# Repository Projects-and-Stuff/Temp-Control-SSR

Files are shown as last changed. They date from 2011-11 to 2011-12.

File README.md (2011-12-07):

# Temp Control SSR #
#### A Solid State Relay designed to switch loads of up to 8A and up to 220VAC ####

I'm designing a Solid-State Relay circuit board which is controlled by a temperature sensor.

The original purpose for this project involves a story: As I'm writing this, I'm deployed in Afghanistan. We have somewhat limited resources for frivolous things, and apparently this extends to keeping foods and drinks cool. We were able to scrounge a freezer, and so we continuously have to open the freezer lid to thaw our milk, water, and foods. It's not the best set-up, but we cannot get a proper refrigerator out here.

So I set out to make a device to cut off the power to the freezer when it's overly cold, and turn it back on before the food gets warm. Because I'm using a microcontroller, I can experiment with carious feedback and control designs in software as I look for the best solution. I've designed the initial boards with terminals for the temperature sensor, so it's possible to modify the firmware for other types of sensors.

---

The current hardware iteration of this project is actually a bit over-engineered and large. A future design will shrink the board to a more manageable size, and reduce costs.

---

*File Structure*

* ./Firmware/ --> Firmware for the project (Written in C Utilizing AVR Studio 5 and AVRGCC)
* ./Hardware/ --> Kicad Project for TempControl Hardware
* ./GerberOutput/ --> The latest Gerber Files for manufacture
* ./Notes/ --> Project Notes, BOM, and Research

---

Additional information, research, and notes can be found at http://www.projectsandstuff.com, or email us at support@projectsandstuff.com

Let us know if you fork and make improvements. We'd be glad to consider merges that improve this project.

---

UPDATES:

Updated Trace widths and clearance per ANSI/IPC-2221A Standards

---

CURRENT AUTHORS:

> [Jack Linke](http://www.jacklinke.com)
jacklinke@gmail.com

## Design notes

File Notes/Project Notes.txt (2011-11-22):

Design specifications:
- No budget, but aim for lower cost
- Over-engineer to ensure survival in rough environments
- Under $100

======================================================
Discuss how I determined the wattage to select for the current-limiting resistors.
Maximum Forward current is 20mA
I want to aim for 10mA
The input voltage is 5VDC
The forward voltage is about 1.7 to 2.2 volts

Now we can run 2 calculations to determine the appropriate range of resistors:
5 - 2.2 = 2.8 / 0.01 = 280 Ohms
5 - 1.7 = 3.3 / 0.01 = 330 Ohms

To verify that anything in this range will meet our needs, we'll check what current values we get if the forward voltage drop across the LED is a bit different than we expected:
2.8 / 330 = 0.085 = 8.5mA
3.3 / 280 = 0.0118 = 11.8mA

Both of these values are well within the allowable current range for the LEDs, and still very near what we were looking for in total current.

When selecting a resistor, one of the specifications is power handling. To determine the maximum power our resistor will have to deal with, we do the following:
- Calculate the maximum voltage drop across the resistor: 5 - 1.7 = 3.3
- Remember that P = I * E
- So for the maximum current that will be passing through our resistor: P = 0.0118 * 3.3 = 0.03894W
- Because I want to over-engineer a bit, I'll double the value, but you should always give yourself a bit of fudge-factor by increasing the value 10-20%
- I'll select the cheapest resistor between 280 and 330 ohms that can handle at least 0.08W

======================================================

Why I chose to use the SCK ISP pin as the driver for the DS18B20 sensor: In order for the sensor to communicate, it must ....

Is it possible that just by seeing a clock on the line it might try to communicate? In which case I need to isolate the sensor from the programmer.

Nope, this is a problem as the 1-wire protocol initializes simply with a puls. So the SCK may be assumed to be the initialization pulse, after which the slave device (the sensor) will pull the line down for another pulse to signal its presence.

Might be able to use the reset line, though? Since during programming it will be held to a single state the entire time, which shouldn't confuse the 1-wire.

======================================================

Seal the circuit board traces to help deal with dust causing shorts

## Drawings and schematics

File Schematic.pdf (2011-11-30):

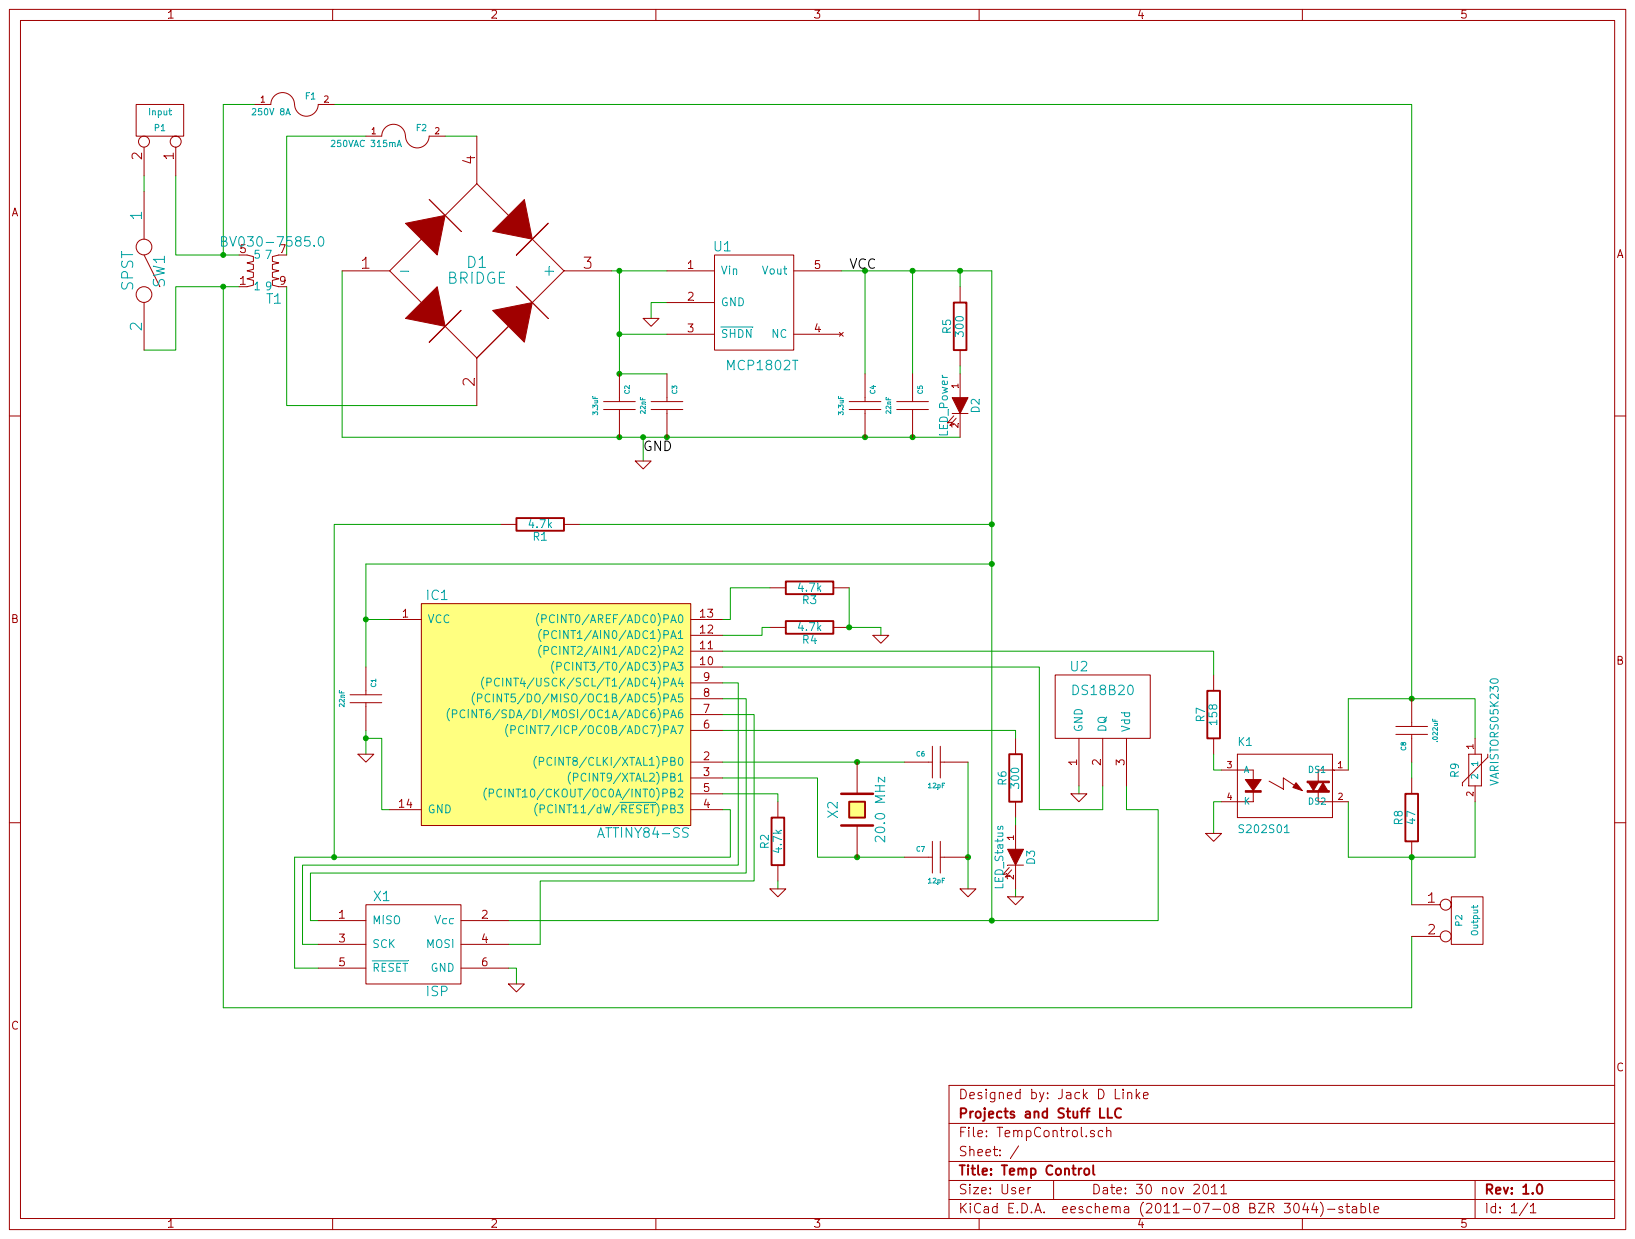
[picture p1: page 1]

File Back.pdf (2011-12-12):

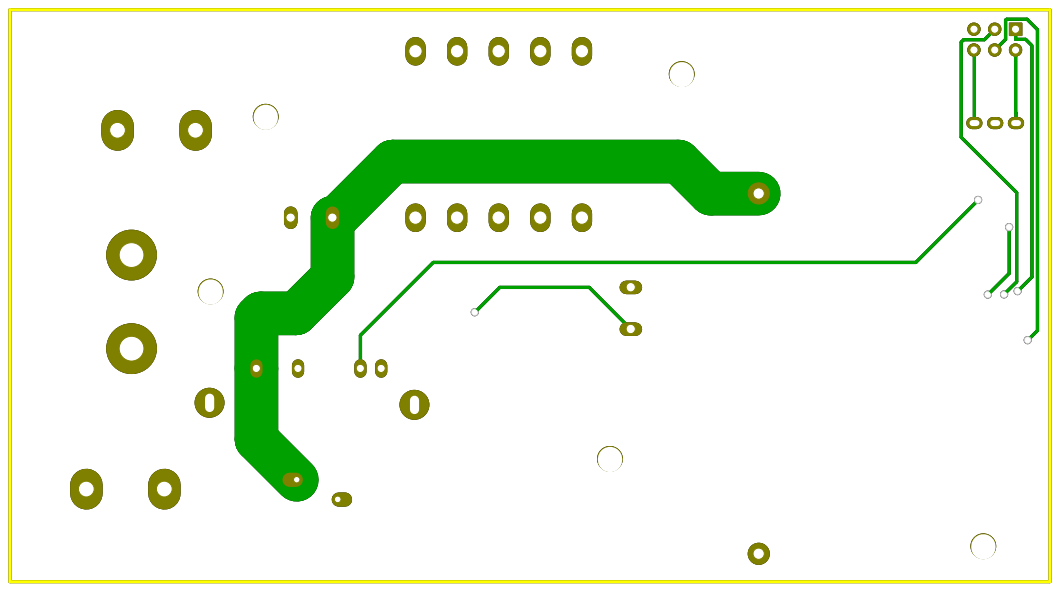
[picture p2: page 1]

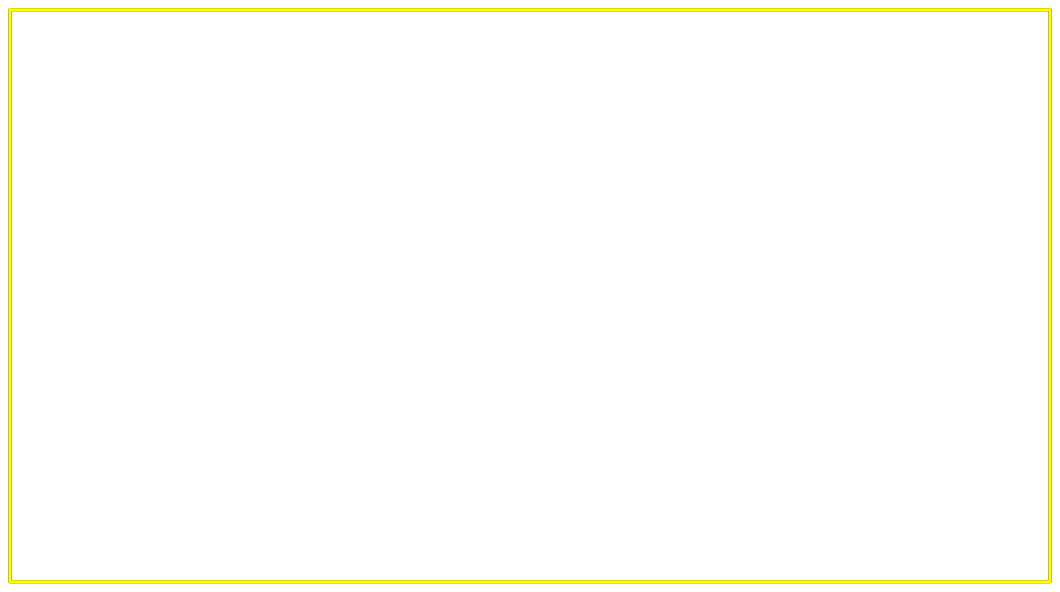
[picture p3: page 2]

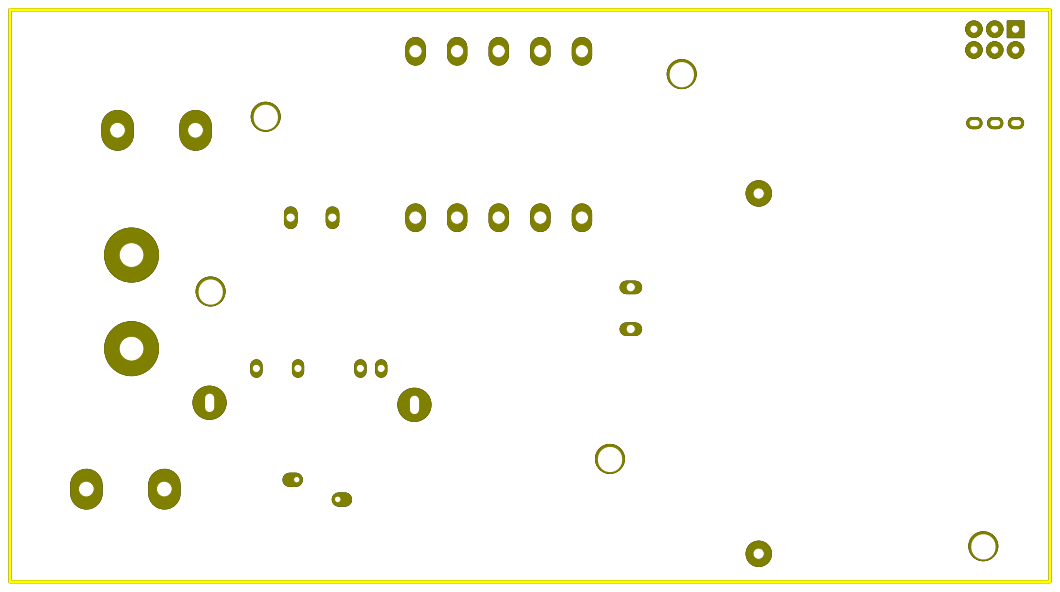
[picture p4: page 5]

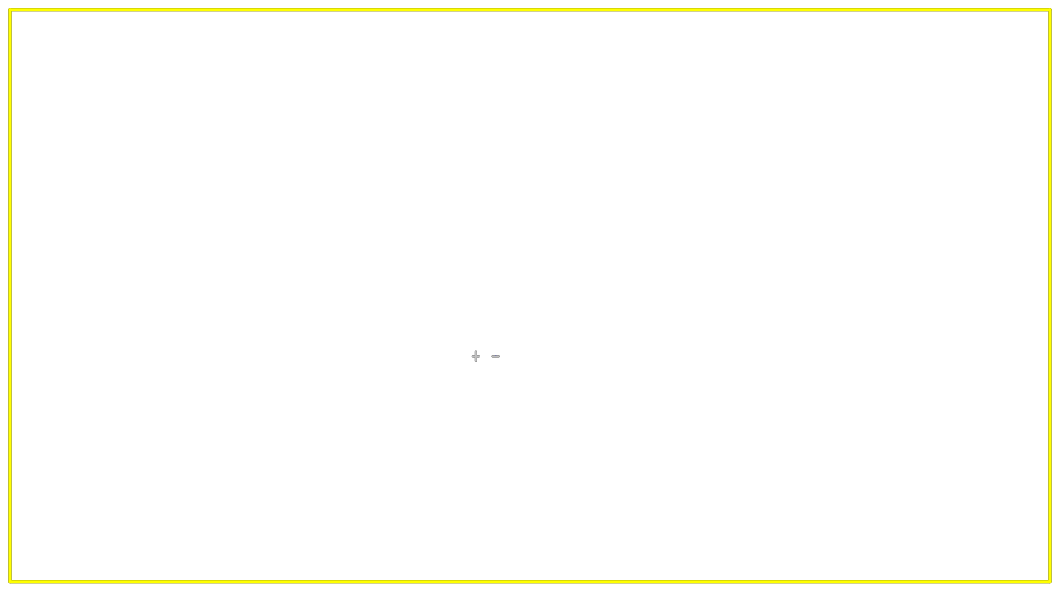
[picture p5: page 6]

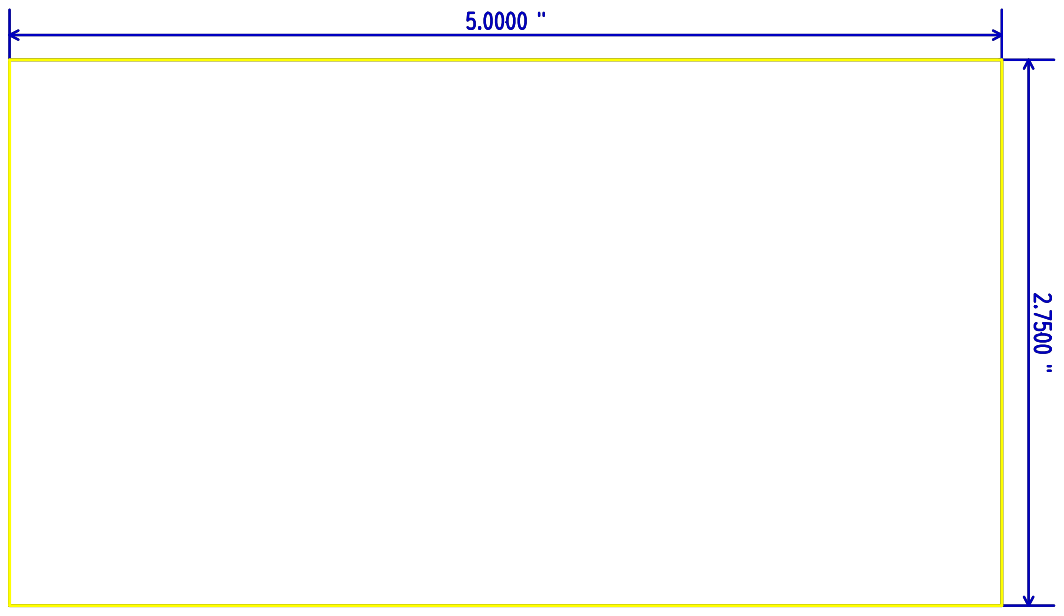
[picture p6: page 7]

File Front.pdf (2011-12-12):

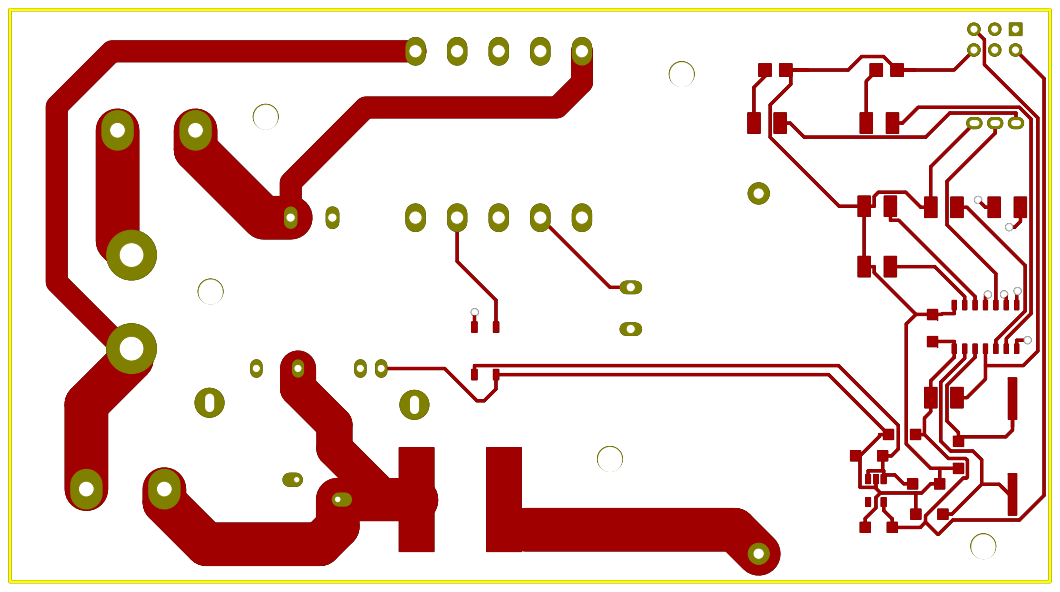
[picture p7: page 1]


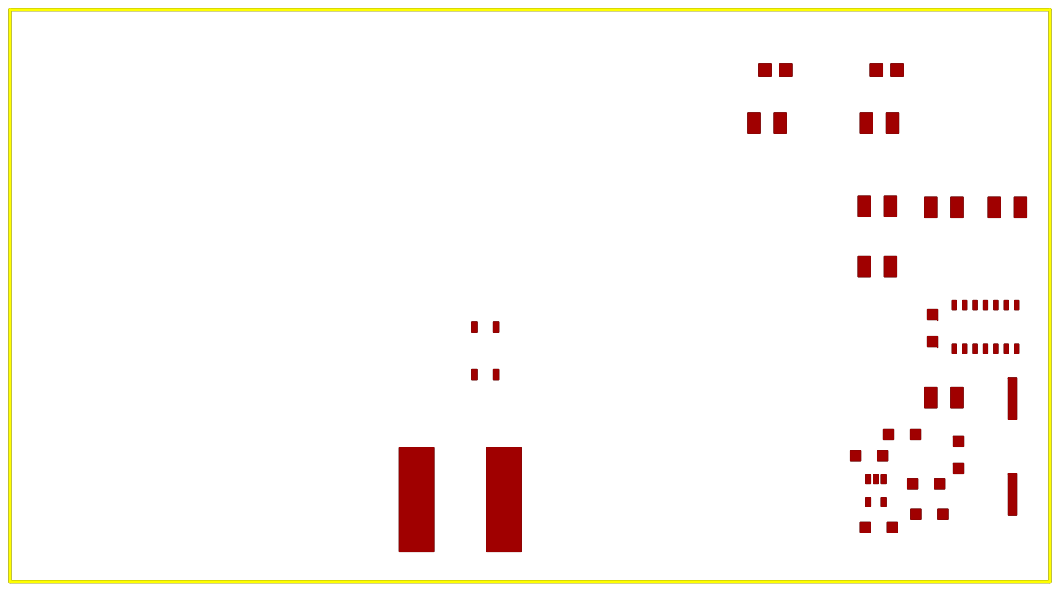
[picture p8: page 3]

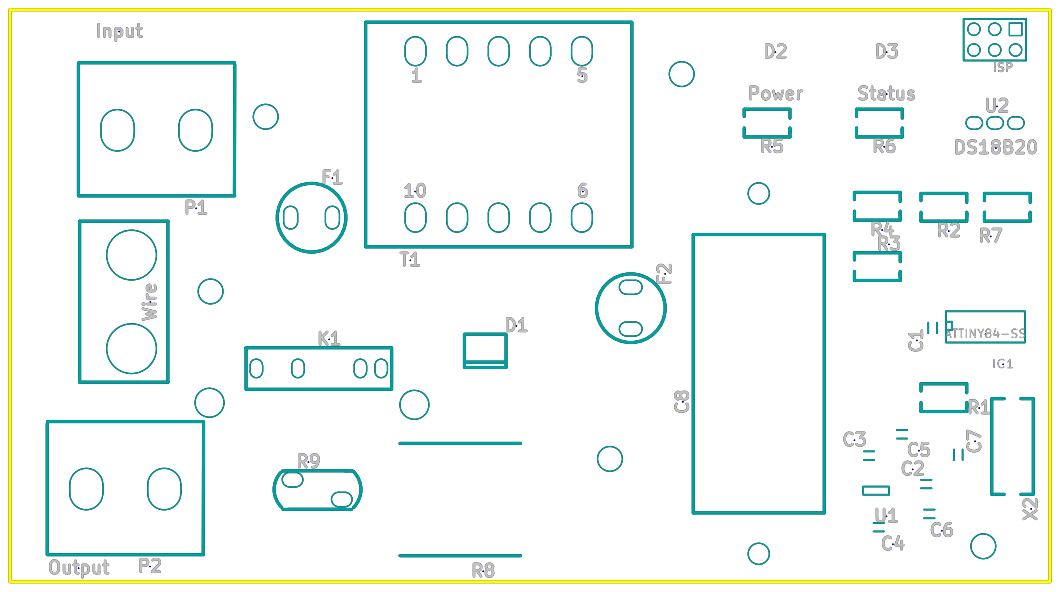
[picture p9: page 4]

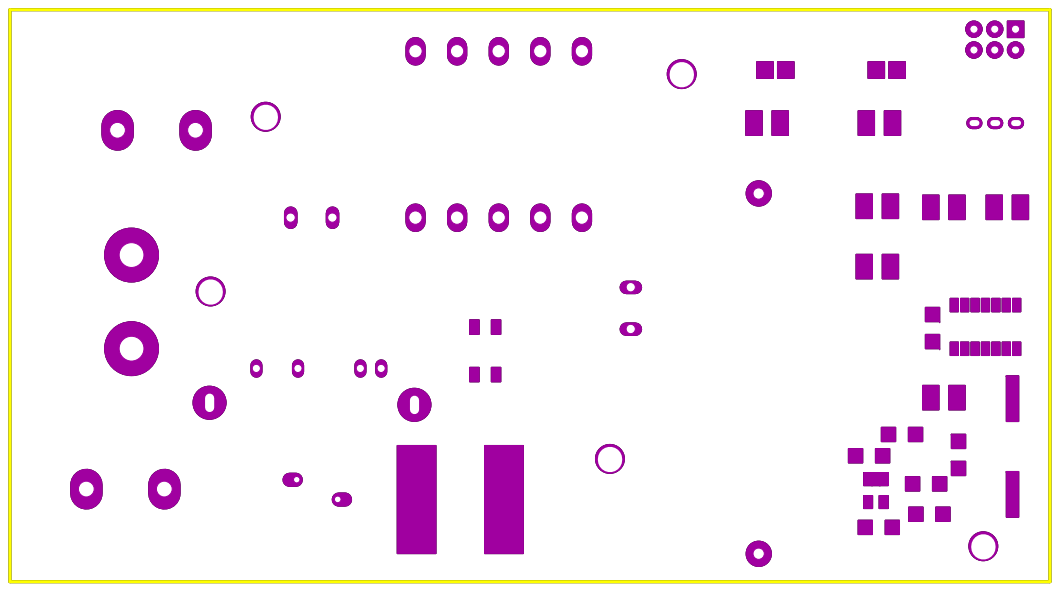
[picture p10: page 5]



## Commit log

2011-11-22 Uploading current file structure
    [$savepcb.brd, TempControl.brd, TempControl.dsn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]
2011-11-30 Standardized Schematics
    [TempControl.sch]
2011-11-30 Updated PCB per IPC and ANSI Standards
    [TempControl-Back.gbl, TempControl-Front.gtl, TempControl-Mask_Back.gbs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]
2011-12-12 Updated board based on newest prototype
    [TempControl-Back.gbl, TempControl-Front.gtl, TempControl-Mask_Back.gbs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]
2011-12-12 Removed extra Gerber files
    [TempControl-Back.gbl, TempControl-Front.gtl, TempControl-Mask_Back.gbs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]
